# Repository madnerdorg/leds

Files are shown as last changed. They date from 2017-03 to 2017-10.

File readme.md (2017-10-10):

[Français](https://madnerdorg.github.io/leds/readme.fr)

Libre Connect   
[Download Leds](https://github.com/madnerdorg/leds/archive/master.zip) /  [LibreConnect](https://madnerdorg.github.io/libreconnect/) /[Source](https://github.com/madnerdorg/leds)

- [What is Leds](#what-is-leds)
- [Applications](#applications)
- [How to build leds](#how-to-build-leds)
- [Commands](#commands)

# What is Leds

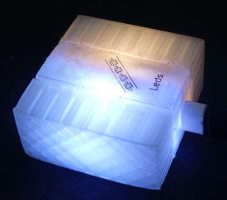
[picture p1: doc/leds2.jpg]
Photo LEDs
   
**leds** is a device to control 1 or more leds (ws2812b) using USB.   
You can animate each leds independently, and change the color using **hsv colors**.  

- [Applications](#applications)
- [How to build leds](#how-to-build-leds)
- [Commands](#commands)

# Applications
> By default , leds are available at ws://localhost:42001

## [apps/html](http://madnerd.org/interface/leds2)  
Control your leds using a webpage    
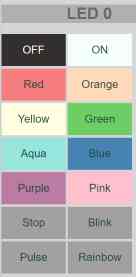
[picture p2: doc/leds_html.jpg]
Photo LEDs
   

## [apps/tasker](https://github.com/madnerdorg/leds/tree/master/apps/tasker)    
Tasker   
Be notified when someone calls you, using [tasker](https://play.google.com/store/apps/details?id=net.dinglisch.android.taskerm) and some easy to use JavaScript.
You can trigger leds for any events that happens on your phone!

You can also use [Power Toggles](https://play.google.com/store/apps/details?id=com.painless.pc) to make buttons on your notification bar.

Power Toggles

Here is a script I use to turn off leds.
* Create a task
* Import your code using Code/Javascript
* Remove auto exit
* Delay set to 1 seconds.

```
ip="192.168.0.140";
port=42001;

bluepulse = "load;255;160;255;143;2;0;0;160;255;116;2;0;0;";
police = "load;255;0;255;255;4;0;1;160;255;255;4;1;70;";
fire = "load;123;32;255;41;2;0;0;32;255;129;2;0;0;";
off = "/off";

leds = new WebSocket("ws://"+ip+":"+port);
leds.onopen = send;

function send(){
	leds.send(off);
}
```

## apps/thunderbird    
Be notified when someone sends you an email, using **filters** and [mail alerts](https://addons.mozilla.org/fr/thunderbird/addon/mailbox-alert/) plugin.

You can use [ws-send](https://github.com/madnerdorg/libreconnect/blob/master/ws-send.py) to control leds.
```
"c:\libreconnect\ws-send.exe" -u "ws://localhost:42001" -m "/on"
```

# How to build leds

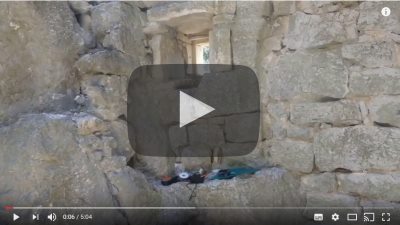
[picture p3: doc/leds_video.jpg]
leds (https://www.youtube.com/watch?v=UThz91hRcYQ)


## Arduino
First we need to copy the code on an arduino, 
* Copy **arduino/leds** and **arduino/library** into your arduino sketchbook
* Upload **leds/leds.ino**

## Components
Here is the list of components, you will need you can easily find it using these keywords on ebay/aliexpress etc...
### led2
* RobotDyn Nano V3 (micro-usb): 2€
### led5
* Arduino nano clone CH340G (mini-usb): 2€
### Strip WS2812B
* 30 leds WS2812B : 4.50€ ( 5 leds :0.75€)
* Resistor pack 400pcs (3€) (1 resistor: 0.0071€)
* Total : 9.5€ (2.75€)

## Wiring
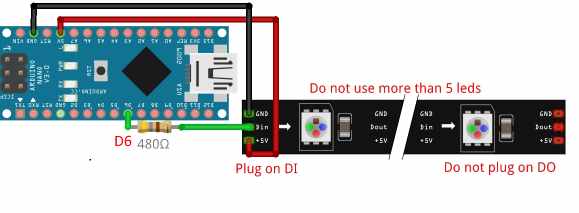
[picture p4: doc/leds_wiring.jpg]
Wiring_leds

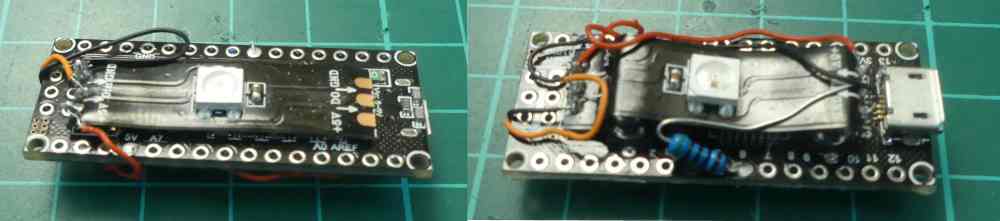
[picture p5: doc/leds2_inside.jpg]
Inside Led2


* D6 --> RESISTOR (470Ω) DI
* +5V --> 5V
* GND --> GND

### Warning
Do not used more than 5 LEDs without a dedicated power supply or this can damage the LEDs, 
Each led can draw up to **60ma** at full brightness   
Arduino can provide up to **500ma** (on 5v/Gnd pin)   
```5 LEDs = 5x60ma = 300ma ```  
Source:
[https://learn.adafruit.com/adafruit-neopixel-uberguide/basic-connections]()

## 3D printing
You will have a more uniform light, if you put the case inside another semi-transparent case.    
![Wiring_leds](doc/leds2.jpg)
![Wiring_leds](doc/leds5.jpg)    
[Models](https://github.com/madnerdorg/leds/tree/master/stl)

# Commands
Here are the commands available, you can send it using Arduino at baudrate 115200.

## Global commands
* /info -------> Give name of device (name:port) (leds:42001)
* /off --> Turn off all leds
* /on --> Turn on all leds
* /status --> Display state of all leds as general_brightness;led0;hue;saturation;value;type_animation;arg1;arg2 etc...
* /load;[status] --> Load the state of leds/animation specified (warning this won't works with 5 leds as the string is too long for serial buffer)
* /save --> Save current state to eeprom
* /reset --> Reset state to eeprom state
* /sync --> Change all value to 255 (max brightness), this will synchronize blink/pulse animation for all leds
* /clear --> Remove settings in eeprom    

### Load example
```
 Fire: load;123;32;255;41;2;0;0;32;255;129;2;0;0;
```
## Leds specific commands
```
color;led;Hue;Saturation;Value ---> Change color for a specific led using hsv
animation;led;type;arg1;arg2 ---> Change animation for a specific led
```
# Color (hue)
Color is hsv have three parameters: hue(color),saturation(more or less white~),value(brightness)
The most important value in hsv is the **hue** which define the color, you can pretty much always use 255;255 for
saturation/value (with the exception of the white color which use 0 as saturation).
* red = 0
* orange = 32
* yellow = 64
* green = 96
* aqua = 128
* blue = 160
* purple = 192
* pink = 224       

## led0 in red 
```
color;0;0;255;255
```
# Animation

![Photo LEDs](https://github.com/madnerdorg/leds/raw/master/doc/leds5.gif)  
* 0: No animation
*  1: Blinking (param1:speed in ms)
*  2: Pulsing
*  3: Rainbow mode
*  4: Alternative Blink (param1:0:master/1:slave, param2:second led/speed in ms)
*  5: Progressive Change (Change color progressively)

## led 0 pulsing
```
animation;2;0;0
```
## led 1 blinking at 25ms
```
animation;1;25;0
```
## led 2 rainbow mode (hue change)
```
animation;3;0;0
```
# Licences

## leds.ino
* Author: Rémi Sarrailh (madnerd.org)   
* Licence: MIT

## FastLed
* Main author: Daniel Garcia (fastled)
* Licence: MIT
* Link : [https://github.com/FastLED/FastLED]()

## Cases (stl)
* Author: Olivier Sarrailh
* Licence: CC-by

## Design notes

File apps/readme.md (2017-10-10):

# Apps/html
Control your leds using this 

This is a one file static web application.
You just need 

# Apps/Tasker

# Modify Leds HTML

To use pug on windows you will need
* Python 2.7
* Nodejs
* Pug
* Pug-cli

# Installation

## Python

* Install miniconda Python 2.7
- https://conda.io/miniconda.html

## Node JS
* Install nodejs
https://nodejs.org/en/download/

* Install pug/pugcli   
npm install --global --production windows-build-tools   
npm install -g pug    
npm install -g pug-cli    

Go to apps\html and type
pug -P -w templates -o ./

It will automatically render all files

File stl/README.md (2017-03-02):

# 3D model V2.1

Model for Universal Led
````By Olivier Sarrailh````

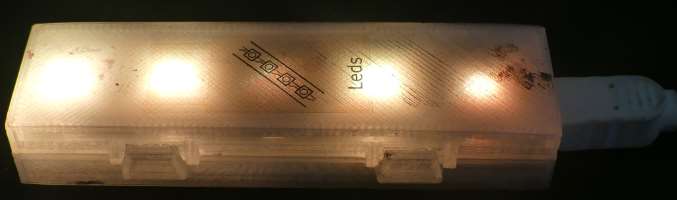
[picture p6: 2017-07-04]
doc/leds5.jpg

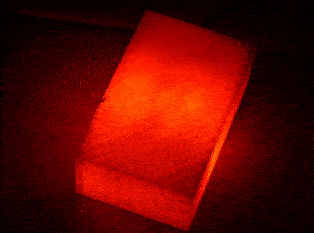
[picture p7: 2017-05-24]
doc/leds2.gif

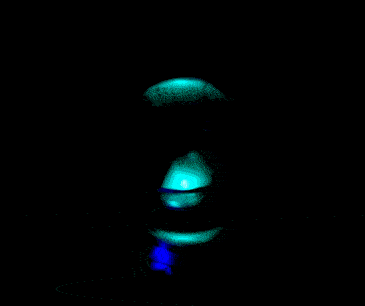
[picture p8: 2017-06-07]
doc/leds5.gif

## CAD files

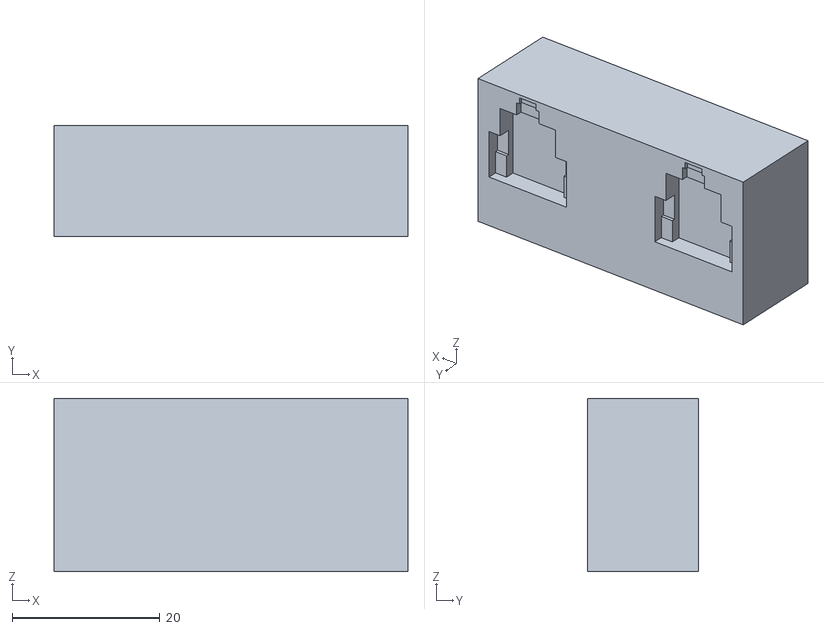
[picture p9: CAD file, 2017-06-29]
stl/led2/Led2_C.stl
48.0 x 15.0 x 23.5

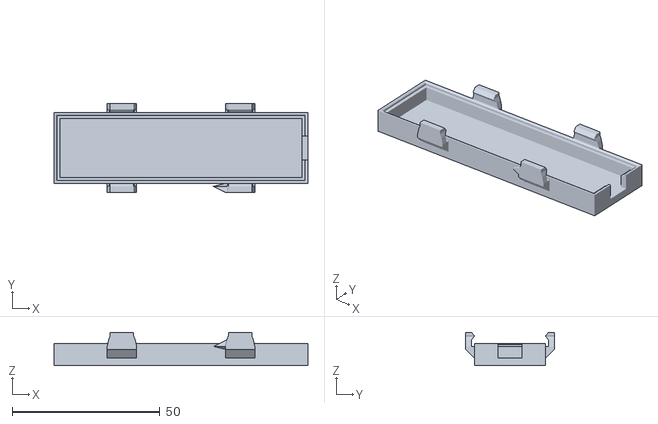
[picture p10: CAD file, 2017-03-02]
stl/led5/Led5_B.stl
86.0 x 30.0 x 11.3

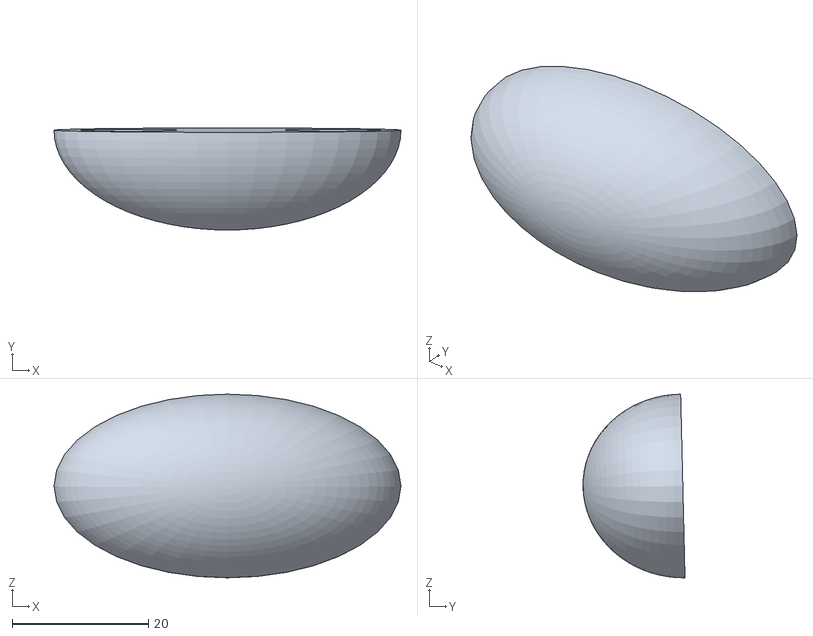
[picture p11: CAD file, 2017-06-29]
stl/led2/Led_C2.stl
51.0 x 15.0 x 27.0

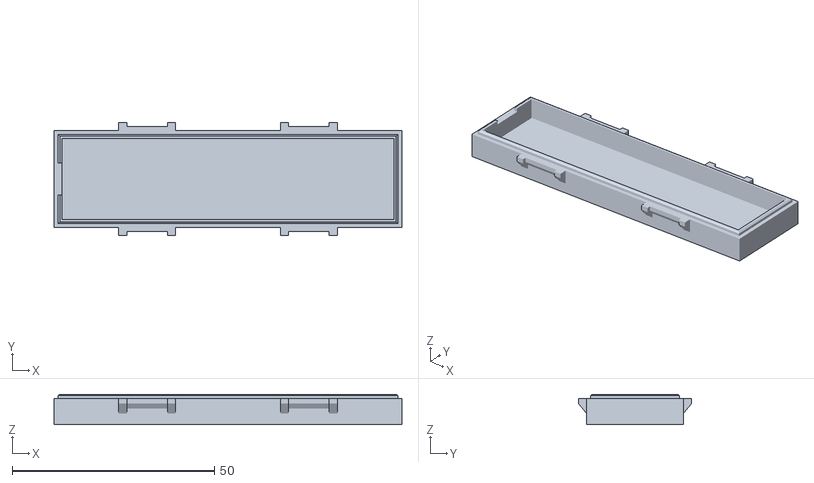
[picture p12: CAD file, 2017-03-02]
stl/led5/Led5_A.stl
86.0 x 28.0 x 7.49

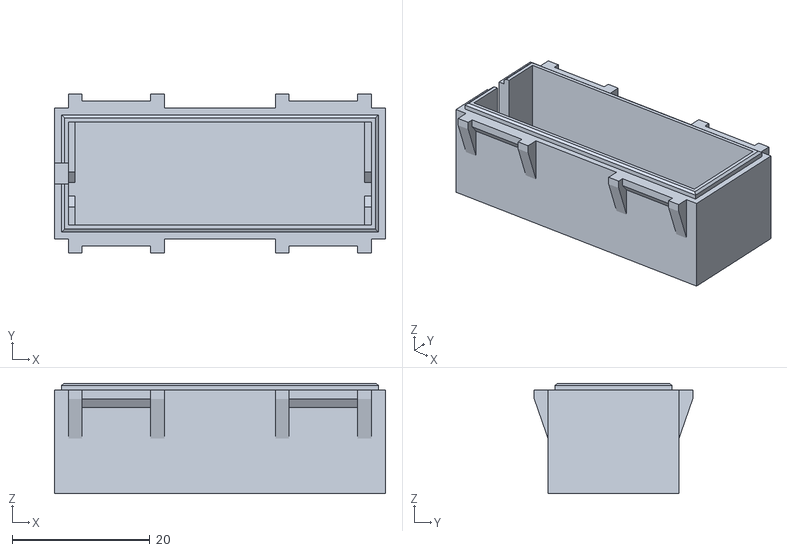
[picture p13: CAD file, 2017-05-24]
stl/led2/Led2_A.stl
48.0 x 23.0 x 16.0

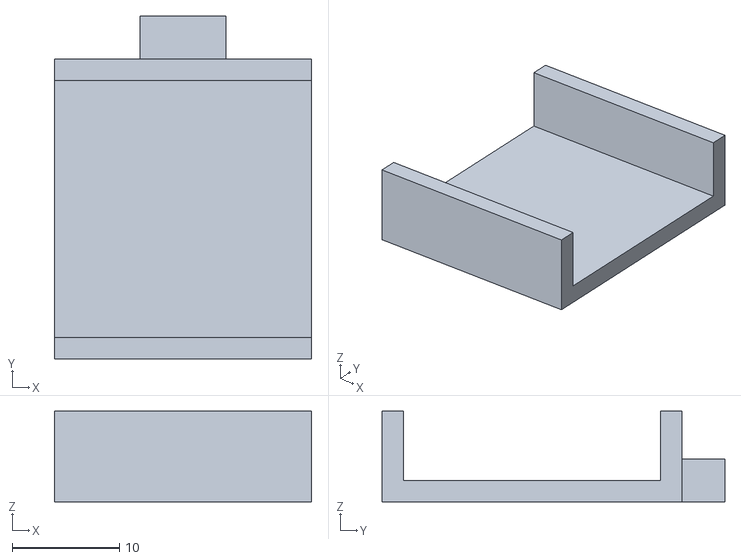
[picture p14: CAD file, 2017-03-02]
stl/led5/Led5_C.stl
24.0 x 32.0 x 8.49

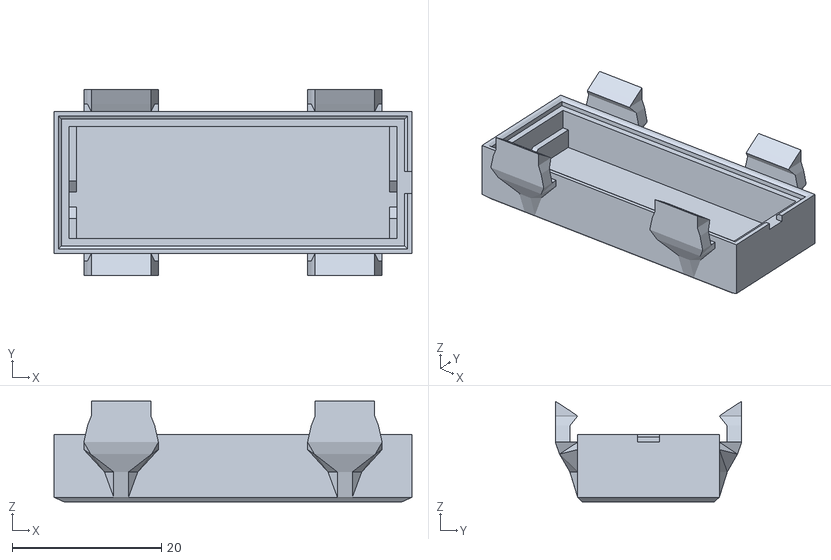
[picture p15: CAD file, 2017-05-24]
stl/led2/Led2_B.stl
48.0 x 25.0 x 13.5

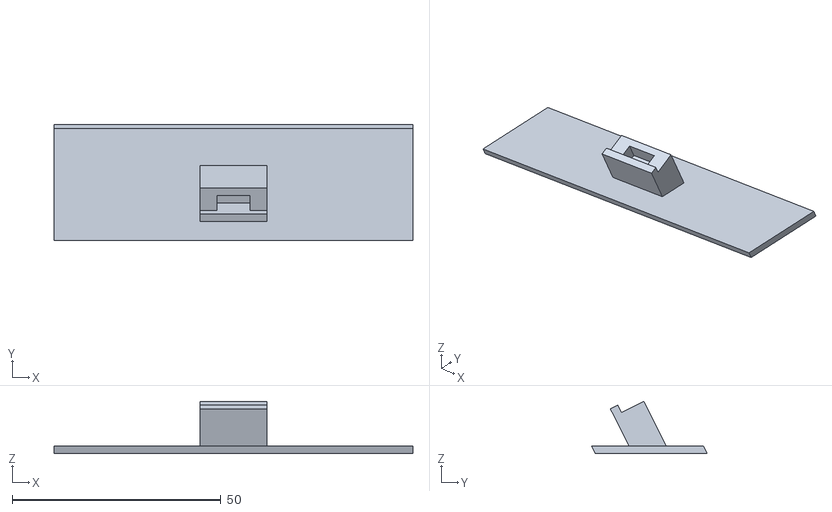
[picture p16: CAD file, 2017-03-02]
stl/led5/Led5_D.stl
86.0 x 27.7 x 12.5

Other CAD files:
stl/led2/Led2.blend
stl/led5/Led5.blend

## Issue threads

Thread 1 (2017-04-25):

HSV controls

maditnerd, 2017-04-25:
I wanted a basic examples to showcase leds but WS2812B can do a lot more than this.
* Colors from hex
* Brightness controls.

We could also manage basic animation with simple commands or go the other way to be able to control the led as fast as possible.

Test a prototype that takes hsv value but hsv value on a web page doesn't render well on a rgb led strip as mentionned by fastled here:
https://github.com/FastLED/FastLED/wiki/Pixel-reference

> Please note - these predefined colors are defined using the W3C RGB definitions. These definitions are designed with RGB monitors in mind, not RGB leds, and so the colors that you get on LED strips may be a bit different than you're expecting. In our experience, the colors are often too pale, or washed out (overly-desaturated).

Closed 2017-05-19.

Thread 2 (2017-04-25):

Convert ULed/HOTSHUD

maditnerd, 2017-04-25:
A cool thing to do with leds, is to scan pixel on a screen in a game to make a custom HUD.
Here is an example that grabs the health of a player and display it on leds.
(that probably doesn't works since there was a lot of changes in the GUI for heroes of the storm that doesn't use websocket)
https://github.com/pigetArduino/uled/tree/master/apps/hotsHUD

We could make a client, that would scan specific pixels on the screen, and use this information to make a led change color depending on what happens in game.
We can't do this with fullscreen game, but windows bordered game works.

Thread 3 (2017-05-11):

Led Box

maditnerd, 2017-05-11:
New led case, will be smaller and won't require to add hot glue to block the arduino.
There will only be two leds.
I'm using a robotdyn nano ch340g (with micro usb)
http://robotdyn.com/catalog/boards/nano_v3_ch340g_compatible_with_arduino_nano_v3/
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

The case is modular so you can add plastic parts to customize the form of the led box.
By using other plastic parts we can give the impression the box produce the light by hiding the leds a little bit.
Using layers of plastic parts will make it less and less bright on each parts creating a shade effects.

maditnerd, 2017-05-18:
To commit

Closed 2017-06-01.

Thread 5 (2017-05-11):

EEPROM save state

maditnerd, 2017-05-11:
Current animation/color for leds should be saved on eeprom so you could use the led box as decoration and reprogram it easily.

maditnerd, 2017-05-18:
To commit

Closed 2017-05-19.

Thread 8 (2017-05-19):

Tasker examples

maditnerd, 2017-05-19:
Code ready to be use
see: https://hackaday.io/project/20664-plug-and-play-connected-devices for doc.

* Explains how to create a task with a javascript file
* Explains why you need to remove autoexit (asynchronous send)
* Explain how to make the leds pulse blue when a message is received
* Explains how to use auto-toggle to make a button to turn off leds.

--> Screencast phone

Closed 2017-05-19.

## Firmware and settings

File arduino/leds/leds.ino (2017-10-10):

// LibreLeds v2

// Change log
// v1.0 4 Animation
// v2.0 5 Animation (progressive mode)

#include <FastLED.h>
#include <EEPROM.h>

/*
  Animation
  0: No animation
  1: Blinking (param1:speed in ms)
  2: Pulsing
  3: Rainbow mode
  4: Alternative Blink (param1:master/slave, param2:led/speed in ms)
*/

// Settings
const String usb_name = "leds:42001";
const int NUM_LEDS = 2;

//Leds Setup
const int DATA_PIN = 6; //WS2812b led

//Constants animation
const int STOP = 0;
const int BLINK = 1;
const int PULSE = 2;
const int RAINBOW = 3;
const int ALTERNATE_BLINK = 4;
const int PROGRESSIVE = 5;

const int MASTER = 0;
const int SLAVE = 1;

//Leds objects
CRGB leds[NUM_LEDS];

//Leds Settings
int hue[NUM_LEDS];
int sat[NUM_LEDS];
int val[NUM_LEDS];
int brightness;

int new_hue[NUM_LEDS];
int new_sat[NUM_LEDS];
int new_val[NUM_LEDS];

// Animation Settings
int anim[NUM_LEDS];
int params1[NUM_LEDS];
int params2[NUM_LEDS];

// Leds Status
int status[NUM_LEDS];
long timing[NUM_LEDS];

// Serial Settings
String command;
String readString; //String Buffer

//Timing
unsigned long currentTime = 0;
unsigned long previousTime = 0;

void setup() {
  // put your setup code here, to run once:
  FastLED.addLeds<NEOPIXEL, DATA_PIN>(leds, NUM_LEDS);
  Serial.begin(115200);
  init_leds();
}

void loop() {
  animation_loop();
  FastLED.show();
  serialManager();
}


//Equivalent of explode in PHP (use for serial commands parsing)
String splitString(String data, char separator, int index) {
  int found = 0;
  int strIndex[] = {0, -1};
  int maxIndex = data.length() - 1;

  for (int i = 0; i <= maxIndex && found <= index; i++) {
    if (data.charAt(i) == separator || i == maxIndex) {
      found++;
      strIndex[0] = strIndex[1] + 1;
      strIndex[1] = (i == maxIndex) ? i + 1 : i;
    }
  }
  return found > index ? data.substring(strIndex[0], strIndex[1]) : "";
}

void change_color_all(int h, int s, int v) {
  for (int i = 0; i < NUM_LEDS; i++) {
    change_color(i, h, s, v);
  }
}

void change_color(int led, int h, int s, int v) {

  if (anim[led] == PROGRESSIVE) {
    //Serial.println("PROGRESSIVE MODE");

    
    new_hue[led] = h;
    new_sat[led] = s;
    new_val[led] = v;
    //Serial.print(hue[led]);
    //Serial.print(sat[led]);
    //Serial.println(val[led]);
    //Serial.print(new_hue[led]);
    //Serial.print(new_sat[led]);
    //Serial.println(new_val[led]);
    
  } else {
    //Serial.println("NONPROGRESSIVE");
    hue[led] = h;
    sat[led] = s;
    val[led] = v;
    new_hue[led] = h;
    new_sat[led] = s;
    new_val[led] = v;
    leds[led] = CHSV(h, s, v);
  }
}

void change_anim_all(int animation, int parameter1, int parameter2) {
  for (int led = 0; led < NUM_LEDS; led++) {
    change_anim(led, animation, parameter1 , parameter2);
  }
}

void change_anim(int led, int animation, int parameter1, int parameter2) {
  anim[led] = animation;
  params1[led] = parameter1;
  params2[led] = parameter2;
  status[led] = 0;
  timing[led] = 0;
}


void animation_loop() {
  currentTime = millis();
  for (int led = 0; led < NUM_LEDS; led++) {

    // Pulse animation
    if (anim[led] == PULSE) {
      //Orientation (fading in/fading out)
      if (val[led] <= 0) {
        status[led] = 1;
      }
      if (val[led] >= 255) {
        status[led] = 0;
      }
      if (status[led] == 0) {
        val[led]--;
      } else {
        val[led]++;
      }
      change_color(led, hue[led], sat[led], val[led]);
      //Serial.println(val[led]);
    }

    //Blink animation
    if (anim[led] == BLINK) {
      //If interval is finish change state
      if (currentTime - timing[led] > params1[led]) {
        timing[led] = currentTime;
        if (val[led] == 255) {
          val[led] = 0;
        } else {
          val[led] = 255;
        }
        change_color(led, hue[led], sat[led], val[led]);
      }
    }

    if (anim[led] == RAINBOW) {
      if (hue[led] <= 0) {
        status[led] = 1;
      }
      if (hue[led] >= 255) {
        status[led] = 0;
      }
      if (status[led] == 0) {
        hue[led]--;
      } else {
        hue[led]++;
      }
      change_color(led, hue[led], sat[led], val[led]);
    }

    if (anim[led] == ALTERNATE_BLINK) {
      //If led is master (ignore if slave)
      if (params1[led] == 0) {
        int led2 = params2[led];
        int interval = params2[led2];
        if (currentTime - timing[led] > interval) {
          timing[led] = currentTime;
          if (val[led] == 255) {
            val[led] = 0;
            val[led2] = 255;
          } else {
            val[led] = 255;
            val[led2] = 0;
          }
        }
        change_color(led, hue[led], sat[led], val[led]);
        change_color(led2, hue[led2], sat[led2], val[led2]);
      }
    }

    if (anim[led] == PROGRESSIVE) {
      if (hue[led] < new_hue[led]) {
        hue[led]++; 
        leds[led] = CHSV(hue[led], sat[led], val[led]); 
        //Serial.println(hue[led]);
        //Serial.println(new_hue[led]);
      }
      if (hue[led] > new_hue[led]) {
        hue[led]--; 
        leds[led] = CHSV(hue[led], sat[led], val[led]); 
      }
      if (sat[led] < new_sat[led]) {
        sat[led]++;
        leds[led] = CHSV(hue[led], sat[led], val[led]);
      }
      if (sat[led] > new_sat[led]) {
        sat[led]--;
        leds[led] = CHSV(hue[led], sat[led], val[led]);
      }
      if (val[led] < new_val[led]) {
        val[led]++;
        leds[led] = CHSV(hue[led], sat[led], val[led]);
      }
      if (val[led] > new_val[led]) {
        val[led]--;
        leds[led] = CHSV(hue[led], sat[led], val[led]);
      }
    }
  }
}

void init_leds() {
  int status_eeprom;
  EEPROM.get(0, status_eeprom);
  if (status_eeprom != -1) {
    read_eeprom();
  } else {
    change_color_all(0, 0, 0);
    change_anim_all(0, 0, 0);
    brightness = 255;
    LEDS.setBrightness(255);
  }
}

void read_eeprom() {
  int address = 0;
  EEPROM.get(0, brightness);
  LEDS.setBrightness(brightness);
  address = 2;
  for (int led = 0; led < NUM_LEDS; led++) {
    EEPROM.get(address, hue[led]);
    address = address + 2;
    EEPROM.get(address, sat[led]);
    address = address + 2;
    EEPROM.get(address, val[led]);
    address = address + 2;
    EEPROM.get(address, anim[led]);
    address = address + 2;
    EEPROM.get(address, params1[led]);
    address = address + 2;
    EEPROM.get(address, params2[led]);
    address = address + 2;
    change_color(led, hue[led], sat[led], val[led]);
    change_anim(led, anim[led], params1[led], params2[led]);
  }
}

void save_eeprom() {
  int address = 0;
  EEPROM.put(0, brightness);
  address = 2;
  for (int led = 0; led < NUM_LEDS; led++) {
    EEPROM.put(address, hue[led]);
    address = address + 2;
    EEPROM.put(address, sat[led]);
    address = address + 2;
    EEPROM.put(address, val[led]);
    address = address + 2;
    EEPROM.put(address, anim[led]);
    address = address + 2;
    EEPROM.put(address, params1[led]);
    address = address + 2;
    EEPROM.put(address, params2[led]);
    address = address + 2;
  }
  //Serial.println("Saved eeprom");
}

void serialManager() {
  while (Serial.available()) {
    delay(5);
    if (Serial.available() > 0) {
      char c = Serial.read();
      readString += c;
    }
  }

  if (readString.length() > 0) {
    if (readString[0] == '/') {
      if (readString == "/info") {
        Serial.println(usb_name);
      }
      //Get status
      if (readString == "/status") {
        Serial.print(brightness);
        Serial.print(";");
        for (int led = 0; led < NUM_LEDS; led++) {
          Serial.print(hue[led]);
          Serial.print(";");
          Serial.print(sat[led]);
          Serial.print(";");
          Serial.print(val[led]);
          Serial.print(";");
          Serial.print(anim[led]);
          Serial.print(";");
          Serial.print(params1[led]);
          Serial.print(";");
          Serial.print(params2[led]);
          Serial.print(";");
        }
        Serial.println();
      }


      if (readString == "/save") {
        save_eeprom();
        Serial.println(readString);
      }

      //Turn off all leds
      if (readString == "/off") {
        change_color_all(0, 0, 0);
        change_anim_all(0, 0, 0);
        Serial.println(readString);
      }

      if (readString == "/on") {
        change_color_all(0, 0, 255);
        change_anim_all(0, 0, 255);
        Serial.println(readString);
      }

      if (readString == "/sync") {
        for (int led = 0; led < NUM_LEDS; led++) {
          val[led] = 255;
        }
        Serial.println(readString);
      }

      if (readString == "/reset") {
        read_eeprom();
      }

      if (readString == "/clear") {
        change_color_all(0, 0, 0);
        change_anim_all(0, 0, 0);
        LEDS.setBrightness(255);
        save_eeprom();
        Serial.println(readString);
      }
    } else {
      String command = splitString(readString, ';', 0);

      //Change brightness
      if (command == "brightness") {
        brightness = splitString(readString, ';', 1).toInt();
        LEDS.setBrightness(brightness);
        Serial.println(readString);
      }

      //Change color
      if (command == "color") {
        int led = splitString(readString, ';', 1).toInt();
        int h = splitString(readString, ';', 2).toInt();
        int s = splitString(readString, ';', 3).toInt();
        int v = splitString(readString, ';', 4).toInt();
        change_color(led, h, s, v);
        //If we turn off led we assume we want to stop the animation too.
        if ( (h == 0) && (s == 0) && (v == 0) ) {
          change_anim(led, 0, 0, 0);
        }
        Serial.println(readString);
      }


      //Change animation
      if (command == "animation") {
        int led = splitString(readString, ';', 1).toInt();
        int animation = splitString(readString, ';', 2).toInt();
        int parameter1 = splitString(readString, ';', 3).toInt();
        int parameter2 = splitString(readString, ';', 4).toInt();
        change_anim(led, animation, parameter1, parameter2);
        //Start Rainbow animation with red
        if (animation == 3) {
          change_color(led, 0, 255, 255);
        }
        Serial.println(readString);
      }

      //Load previous state
      if (command == "load") {
        int cursor = 1;
        brightness = splitString(readString, ';', cursor++).toInt();

        for (int led = 0; led < NUM_LEDS; led++) {
          int h = splitString(readString, ';', cursor).toInt();
          cursor++;
          int s = splitString(readString, ';', cursor).toInt();
          cursor++;
          int v = splitString(readString, ';', cursor).toInt();
          cursor++;
          int animation = splitString(readString, ';', cursor).toInt();
          cursor++;
          int parameter1 = splitString(readString, ';', cursor).toInt();
          cursor++;
          int parameter2 = splitString(readString, ';', cursor).toInt();
          cursor++;
          change_color(led, h, s, v);
          change_anim(led, animation, parameter1, parameter2);
        }
        Serial.println(readString);
      }

    }
    readString = "";
  }
}

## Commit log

2017-03-02 Convert uleds to leds
    First commit
    [ULed.blend, ULed_A.stl, ULed_B.stl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]
2017-04-04 Update doc/code
    [leds_wiring.fzz, universalLed_wiring.fzz]
2017-05-19 Complete rewrite of leds.ino
    -- Animation
    -- EEProm
    -- HSV Control
    -- Serial communication rewrite.
2017-05-23 Move arduino files into its own directory.
2017-05-23 copy from local to remote
    [Led5.blend, Led5.stl, Led5_A.stl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]
2017-05-24 Add 3D models for Led2
    Made by Olivier Sarrailh.
    [Led2.blend, Led2_A.stl, Led2_B.stl]
2017-05-24 [STL] Rename 3D with STL
    [Led2.blend, Led2_A.stl, Led2_B.stl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]
2017-05-26 [DOC] Readme english update to led 2.0
2017-06-06 [DOC] Inverted components -> arduino in readme
2017-06-07 [doc] - update link to stl
2017-06-07 [doc] wrong image for leds5.gif
2017-06-29 [STL] Rename files
    [Led2_C.stl, Led5_D.stl, Led_C2.stl]
2017-06-29 [Arduino] Bug fixes
    - When changing color to black, stop animation.
    - When Rainbox selected, start at color Red. (avoid rainbow to not start)
    [leds.ino]
2017-06-29 [html] Remove leds.html
2017-06-29 [html] Add comments in leds.js
2017-07-04 [Doc] add images leds5
2017-07-10 [Doc] add link to video (wiring)
2017-10-10 Leds v2 - Add progressive animation (5)
